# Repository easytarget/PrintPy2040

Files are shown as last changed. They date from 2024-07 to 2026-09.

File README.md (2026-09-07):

### Same Idea; different MCU
(this project is a 2024 re-working for my original, obsolete,  [PrintEYE](https://github.com/easytarget/PrintEye) project.)

# Proudly Presenting the PrintPy.

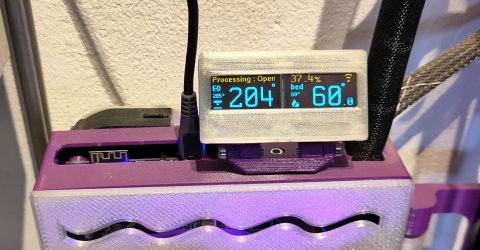
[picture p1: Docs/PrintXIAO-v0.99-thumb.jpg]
PrintXIAO in action


A dedicated Output / Display device for 3d printers running RepRapFirmware v3.4.0 and later.

It displays the current machine mode, current job status, network status, info messages and temperature plus status of the extruder and chassis heaters.
* Supports Single or Dual extruders.
* Supports Heated beds and Heated Chambers.
* Shows when a heater is in a fault state

It uses two OLED displays for it's output, and these can be configured to turn off automatically in certain states (eg *off* / *idle*).

There is a button on the rear of the unit; this can wake the display for a (configurable) time when pressed.

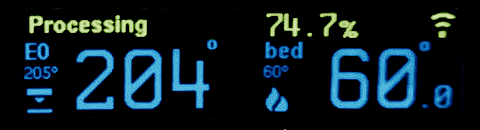
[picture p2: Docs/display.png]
Display detail


Wifi / Ethernet connection status is displayed, and the rear button can enable or disable the network as appropriate on a long press (configurable).

Messages set by `M117` and `M291` are displayed in a scrolling box along with the machine state.

Job progress is displayed when *processing*, *simulating*, *paused* etc.. The IP address or interface (error) status is displayed otherwise.

The onboard NeoPixel on the XiAO board is used to flash the current status after each update; it changes color depending on the printer 'mood':
- 🔴 Red for machine or network *errors*, 🟡 Yellow for *off*, 🟢 Green for *idle*, ⚪ White while *busy*, 🟣 Purple when *processing* jobs and 🔵 Blue for *paused* states.

# Hardware
This is designed to be a relatively simple build using commonly available inexpensive parts.

It needs some soldering and 3d printing skills, and care, but little more; there are no custom PCB's or parts.

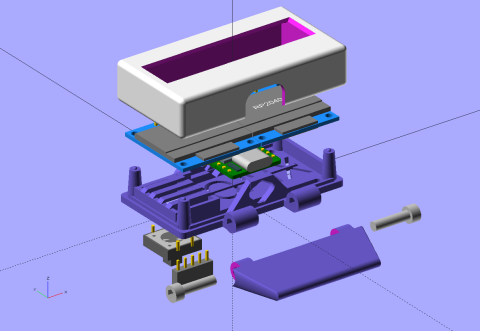
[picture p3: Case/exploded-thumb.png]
Case Render


An alternate, angled, 'foot' design with a mounting hole is included in the models; the upper case is printed from Neutral (translucent) material to allow the NeoPixel to be seen.

See the [HARDWARE](HARDWARE.md) document for a parts list, important construction notes, wiring diagrams and more.

# Software
Code for the SeeedStudio XIAO RP2040 is in the [micropython](microPython) folder.

The code represents the majority of the work needed to create this, the hardware is simple, the code less so. It is written in a well structured and modular way; the output is driven by self-contained classes that can be used as templates for alternative displays and hardware.

See the [micropython README](microPython/README.md) document for install and comissioning details; plus some architecture / development notes.

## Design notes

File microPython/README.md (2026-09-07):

# Micropython code
PrintPY is coded in [MicroPython](https://micropython.org/); and is intended to be uploaded by the user from a suitable IDE (tested with Thonny, but ViperIDE is also nice for more experienced developers).

* If this is new to you I suggest you start with the [XIAO2040 micropython guide](https://wiki.seeedstudio.com/XIAO-RP2040-with-MicroPython/) from SeeedStudio, and use [**Thonny**](https://thonny.org/) as an IDE.
 * You do not need to know Python programming, updating the firmware is drag-n-drop in your file manager, the IDE's are easy to use.
* [**Viper IDE**](https://viper-ide.org/) is also excellent; it runs from the web directly in your web browser without needing to be 'installed'.

Just as the Hardware document assumes you can 3d Print, solder and read a wiring diagram; this document assumes you can follow the guides, set up and connect to your device without needing super detailed instructions here; the guide above will show you what you need.

# RRF config:
You need to set up the second serial (UART) port on your printer to 'no CRC/checksum, 230400 baud'.
* For testing you can use the console to send:
* `M575 P1 B230400 S0`
* For a Duet2 or 3 machine using the default (panelDue) UART interface your `config.g` needs to include that line.
  * This can normally go after the USB port setting (*M575 P0 ....*) line.
  * Later Duet models have additional UART ports that could be used; you will need to adjust ['M575'](https://docs.duet3d.com/User_manual/Reference/Gcodes#m575-set-serial-comms-parameters) as necesscary for them.
* Do not omit or change the `S0` parameter; PrintPY is not compatible with CRC or Checksumming.

# RP2040 MicroPython Firmware:
Hold the 'boot' button on the XIAO board while connecting it to a USB port on your computer; it will appear as a new disk drive (just like a USB thumb drive).
* Flash with the Firmware `.uf2` file in the 'Firmware' folder by dragging and dropping that onto the XIAO drive. The XIAO will pause for a few seconds ingesting the file, then reboot.
  * ..or you can use a later firmware from the main MicroPython site
  * the version in this repo is the Firmware I have tested with
* After sucessfully flashing you should see the REPL console of the device in your IDE:
```python
  MicroPython v1.29.0 on 2026-08-24; Raspberry Pi Pico with RP2040
  Type "help()" for more information.
  >>>
```
# Installing:
Upload all the `.py` files from this directory onto the root folder of your device in the IDE; also copy the fonts directory to 'fonts'.
* The 'Firmware' folder should not be copied; you don't need to copy the README's either..

## Initial Configuration:
Copy `config-default.py` to `config.py` on the device.
* If you are using alternate hardware pins etc. you will need to adjust the hardware config definitions here
* See the [config](#Config) section below for more.

# Test Hardware:
*Note: The hardware test script will read its configuration from the config file we created above.*
* Run `hwTest.py`:
```console
Testing printXIAO comms, screen, pixel and button
UART initialised
Button present on: GPIO2
sent: M122
recieved: b'{"seq":28720,"resp":"=== Diagnostics ===\\n"}\n{"seq":28721,"resp":"RepRapFirmware for Duet 2 WiFi/Ethernet version 3.5.4 (2024-11-24 10:43:42) running on Duet WiFi 1.02 or later\\n"}\n{"seq":28722,"resp":"Board ID: UUID\\n"}\n{"seq":28723,"resp":"Used output buffers: 3 of 26 (16 max)\\n"}\n'
button: Pressed
sent: M122
recieved: b'{"seq":28810,"resp":"=== Diagnostics ===\\n"}\n{"seq":28811,"resp":"RepRapFirmware for Duet 2 WiFi/Ethernet version 3.5.4 (2024-11-24 10:43:42) running on Duet WiFi 1.02 or later\\n"}\n{"seq":28812,"resp":"Board ID: UUID\\n"}\n{"seq":28813,"resp":"Used output buffers: 3 of 26 (16 max)\\n"}\n'
sent: M122
..etc..
```
* You should see the OLED displays outlined and showing 'left' and 'right' as appropriate; the NeoPixel shuld be cycling R->G->B, if you press the button you should see a 'button: pressed' message on the REPL console.
* The script sends [`M115`](https://docs.duet3d.com/User_manual/Reference/Gcodes#m115-get-firmware-version-and-capabilities) every few seconds to the connected RRF machine; and then returns the (JSON encoded) output to the REPL console:

If you do not see any serial output the first thing to do is test (swap) the polarity of the RX and TX lines by reversing the connector on the PrintPY.
* The second thing to test is that both the PrintPy and RRF controller have the baud rate configured properly.

If you see:
```console
Failed to start displays!
[Errno 5] EIO
```
..this indicates a wiring or configuration problem with the OLED displays, the I2C controller is failing to get a response from them during initialisation.

# Commissioning:
Once the test script is running correctly you can try running `printXIAO.py`. You should now see a brief splash-screen and then the current printer status displayed. On the console you should see:
```console
printXIAO is starting
UART initialised
starting output
connected to ObjectModel
button present on: GPIO2
PrintPY::printXIAO is running
[519ms, 112000b] Up: 3d:12h:52:47 | Off | ip: 10.0.0.30
[504ms, 112000b] Up: 3d:12h:52:48 | Off | ip: 10.0.0.30
[505ms, 112000b] Up: 3d:12h:52:49 | Off | ip: 10.0.0.30
etc..
```
The (default configured) status lines show:
* [Fetch cycle time, free memory after fetching and collect()ing]
* Uptime reported by the Controller firmware
* Main status | Wifi Status | Job Progress (if any) | System messages (if any)

The Neopixel will be flashing with the printer 'mood', the heartbeat LED should be cycling as requests are sent.

## Dealing with multi-thread reset errors on the RP2040!
This is annoying; the RP2040 micropython port does not handle multi-cpu systems properly when they have threads running on the second CPU.

*Once the main printXIAO code is running you can interrupt the main loop by pressing **ctrl-c** in the REPL console, but this fails to fully 'soft reset' the board.*
1) *'Crtl-c' in the repl console should be followed immediately by running `machine.reset()` to fully reset the hardware.*
2) *or Press the reset button on the XIAO board (it's tiny and hard to access, especially once the wiring is done, use a small non-conductive plastic rod to do this)*
3) *or Force the reset by unplugging it completely from the printer and usb-c.*

*If you do not do this there is a high chance the board will quickly stop responding to REPL commands; it gets into some sort of bad USB state. This plagued me during the last stages of development.*

# AutoStart at boot
Enable running at boot time by editing the last four lines of the config as described in the comments. Then mount on your machine, close the case, and enjoy seeing your printers status at-a-glance.

*Once Autostart is enabled the multi-thread errors discussed above are more serious since the code is starting automatically. The solution is pressing **ctrl-c** quickly after the reset/reboot, before the main code loop starts. This is why there is a startup countdown, to give console users a chance to interrupt the code *before* the second CPU thread starts.*

# Architecture
`printXIAO.py` is the main program; it runs a continual loop that queries the RRF controller to fetch the current objectModel (machine state). It then calls two output class modules to display data from the objectModel:
- `lumenXIAO.py` : Shows the controller status using the onboard NeoPixel on the Xiao RP2040 board.
- `heartbeatXIAO.py` : Shows a communication 'heartbeat' using the auxillary RGB led on the board.
- `outputI2Cx2.py` : Displays the machine state on a twin OLED display, showing the overall status; current temperatures and heater statuses; job status (when active), messages and network status.
  - The display is built entirely out of fonts (using symbol fonts where necesscary) and uses my own microPython fonts, font writer and marquee.
  - Single or Twin extruders are supported, as are systems with enclosures.

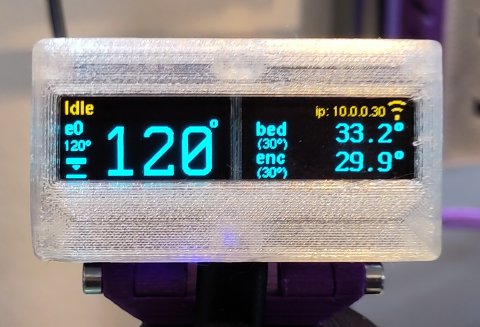
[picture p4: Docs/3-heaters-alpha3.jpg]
Alpha demo


# Requirements:
There are no external dependencies or requirements needed, this folder contains the `printXIAO` code itself and all the libraries it uses.

### SerialOM
Development of the communications code happens in the `serialOM` repo:
https://github.com/easytarget/serialOM

### EZfont Libraries and fonts are in the `fonts` folder
Development of the Font display system (Font Writer, Marquee and the Fonts themselves) happens in the `microPyEZfonts` repo:
https://github.com/easytarget/microPyEZfonts

## Config
As noted above, you need to copy `config-default.py` to `config.py` in the root folder of your device.

Then make any changes you might want.
* See the comments in the config file.
* There are not many 'user options' to play with, and the defaults are set up sensibly for the XIAO 2040 board used here.
* You can set the list of states where the Display should turn off:
  * OLED displays can [burn in](https://forum.makerforums.info/t/oled-display-burn-in-the-evidence/90223) if left on all the time, making the output look reaaly ugly!
  * Turning the displays off when the Printer is `off` is a very good idea.
  * If your printer is permanently on it may be a good idea to add `[idle]` as well as `[off]` to the list of screen off states.
* Another important option here is the Baud rate for the serial port; you must match the speed with the speed configured on your controller. The default baud rate for PrintXIAO is 230400 baud, no parity.
* Only mess with the Hardware settings if you are using alternate wiring or boards etc..
* Do not try to 'speed up' the main (once per second by default) fetch/update cycle too much, the cpu needs at least 500ms to do each fetch cycle, plus 150ms to render the updates to the display panels.
* NeoPixel and display brightnesses can be set, you may want to reduce these in a dark workshop. You can set a different brightness for 'off states'.
* The default network interface can be defined (for controllers with more than one) as can the default commands sent to enable/disable the network.

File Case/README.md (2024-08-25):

# A PythonSCAD based case design.

[PythonSCAD](https://pythonscad.org/)

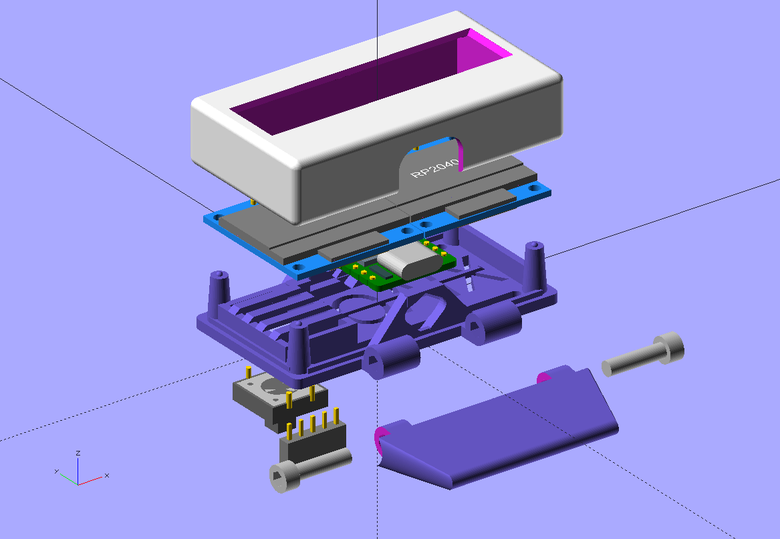
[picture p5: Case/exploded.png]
Case Render


This is also the beginning of a pythonSCAD parts library for my projects

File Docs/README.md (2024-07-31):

## PrintPy notes and references

# Useful Links

ObjectModel reference:
https://github.com/Duet3D/RepRapFirmware/wiki/Object-Model-Documentation

How to detect Object model updates:
https://forum.duet3d.com/topic/16703/suggestions-for-the-object-model/3
https://forum.duet3d.com/topic/30448/how-to-detect-board-disconnection/2

Good background:
https://forum.duet3d.com/topic/25300/how-to-dump-the-entire-object-model

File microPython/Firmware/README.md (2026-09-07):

# Reference firmware package from micropython download site

A copy is kept here for reference; this is the current firmware I am using on my RP2040, and the code has ben extensively tested on this.

```
SEEED_XIAO_RP2040-20260824-v1.29.0.uf2
```

This Upstream (vanilla) firmware was downloaded from the MicroPython downloads page:
https://micropython.org/download/SEEED_XIAO_RP2040/

The `SEEED_XIAO_RP2040-20260824-v1.29.0.atexit.uf2` firmware was built by me; it enables the `atexit()` function within micropython for catching all `exit()` events. This is handy for stopping threads, cores and timers in multi-thread code such as PrintPY; and is detected and used to give smoother debugging if available.

Now this project is released I do not intend to track, upgrade and test every new MicroPythoin release.

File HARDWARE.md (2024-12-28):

# HARDWARE GUIDE FOR PrintXIAO
## the the default PrintPY implementation

Case Render

## Parts:
1. A SeeedStudio XIAO RP 2040 devboard
2. Two SSD1306 OLED I2C displays; the yellow/blue displays I use in my project work well, but any color display of the same size will work.
3. Hookup wire; thin.
4. (optional) A press Button; the design used here is quite common, the case has enough space to accomodate other types
5. (optional) A 5-pin du-pont socket strip, I had to cut down and trim a longer strip.
  * Alternatively you can have a direct wire from the PrintPY to the board, depending on needs.

You will also need a UART cable suitable for your board, the cable below is for a Duet2.
* The Duet3+ ranges use a different JST plug on the board. This has 3.3v available avoiding the need to bring 5V to the PrintPY, see the notes at the end of this document for more

## Case
The case needs care when slicing and printing, some of the clearances are very tight. use a slicer with adaptive layer height features to make sure the screens and PCB's fit correctly.

Print the upper case from neutral translucent material if you can. The onboard NeoPixel 'mood indiator' will then illuminate the whole body. You could also cut 'windows' in the case for illumination, or disable the mood lighting entirely in the config if not wanted.
- There are two upper case models included. One has a cutout allowing access to the XIAO USB-C port (for developing and debugging) while the other is a continuous shell and will probably print 'better' (fewer atrifacts in the translucent print) and grip in place more securely. ymmv.

The STL file has all the components included and orientented correctly, edit it in your slicer to select only the components you are going to print.
- There are two 'foot' designs included, one for freestanding use, the other is more suited to a frame mounting.

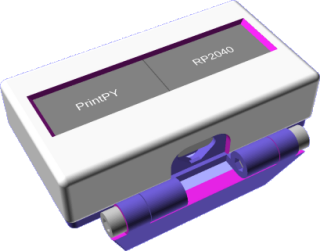
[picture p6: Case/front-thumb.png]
Case Render
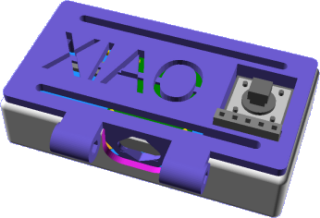
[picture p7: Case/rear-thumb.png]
Case Render
 

There are *three* case sizes, I used the 'slim' case, the only difference for the 'normal' and 'large' varients is that they add 2mm and 4mm (respectively) of additional depth (wiring space) between the screens and the Xiao/connections.
- I recommend using the 'normal' case, the slim design packs the hookup wiring *very* tightly and is hard to get cosed without springing back open (I eventually lightly glued mine together once I'd verified all the wiring, buttton etc).

### Important Construction Note:
Print the top case from a translucent material to allow the Neopixel and heartbeat LED's to be seen through the case.

You need to 'mask' the gap between the two OLED displays, otherwise this will look ugly with a bright light coming through the gap.
- Use a strip of opaque tape, I cut a strip of very ordiary black electrial tape for this.
- I then placed tape across all the exposed electronics on the back of the display to insulate them and then placed a strip of silver foil on that so that the NeoPixel is reflected back to maximize the lighting effect.

You also need to mask (or remove) the 'Super Brite!' 5V power LED on the Xiao board. This destroys the lighting effect otherwise.
- To be honest; Seeedstudio screwed up here. They put this very bright LED right next to the relatively dim RGB status LED that I use for a 'heartbeat' display. The RGB is essentially invisible when the board is running from a 5V supply.
- I cut and heat-formed a very small square of black plastic which is glued in place, this was fiddly since the LED also shines out sideways from it's package, so I had to make a 'cap' that fits over it.
- Desoldering it would be preferable, but it is in a very fiddly location and extremem cre would be needed, plus a good magnifier.

After wiring consult the code install and comissioning document *before* you close the case and mount the unit. As well as attaching a USB-C cable for programming, you will need to access the reset button on the XIAO board as part of comissioning.

## Wiring 5V (Duet 2)
Hookup Guide

There is no PCB needed for this, the circuit should be wired + soldered directly in-place using thin hookup wire (this is fiddly, but possible)

## Connecting to Duet / RRF board.
PrintPY connects to the UART (serial) port on your board. It needs a Power Supply, ground and TX/RX connections.

[The documentation for the PanelDUE also gives a good overview of connecting serial to the Duet boards, there is a specific PanelDue `UART` socket on the Duet2 (wifi), and the `IO_0` socket on the Duet3 boards.

### Connection Looms; 5V (Duet)
Take care with wiring this, it is important that the 5V supply does not contact the (3v3) TX/RX lines! The connector allows the plug to be reversed to swap TX/RX lines quickly and safely.

#### Duet 2
Duet2 Loom

#### Duet3
Duet3 Loom
(Serial connection loom diagrams were generated by [wireviz](https://github.com/wireviz/WireViz) from the `.yaml` descriptions [here](Docs/wireviz_uart_duet2.yaml) and [here](Docs/wireviz_uart_duet3.yaml))

### 3.3V Looms
If you have a board with a 3.3v pin on the uart connector (like the Duet3) you can adapt the main wiring so it does not use 5V at all:
- Leave the 5V pin on the XIAO unconnected
- Bring the 3.3V power rail to the rear connector of the PrintPY in place of the 5V one
- Adapt the Duet3 loom (above) as needed..
- I leave this as an excercise for the reader..

## Alternate connections/deployments
The software is pretty modular; the OLED displays and NeoPixel are driven by self-contained classes. The main PrintPY code loop updates the local objetModel and then calls the lumen and display modules; the modules themselves decide what to display based on the current objectModel status.

It would be relatively easy to re-write the `output` and `lumen` modules for other displays and purposes.

### RP2040 I2C pins
If using an alternate RP2040 board please check the table below to determine which pins the I2C interfaces can be accessed on; and make sure the pins are correctly defined in the code.
```
I2C0 – SDA : GP0 / GP4 / GP8  / GP12 / GP16 / GP20
I2C0 – SCL : GP1 / GP5 / GP9  / GP13 / GP17 / GP21
I2C1 – SDA : GP2 / GP6 / GP10 / GP14 / GP18 / GP26
I2C1 – SCL : GP3 / GP7 / GP11 / GP15 / GP19 / GP27
```

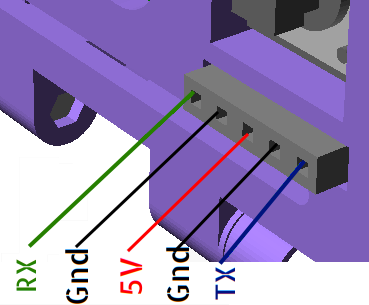
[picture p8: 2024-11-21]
Docs/uart-connector.png

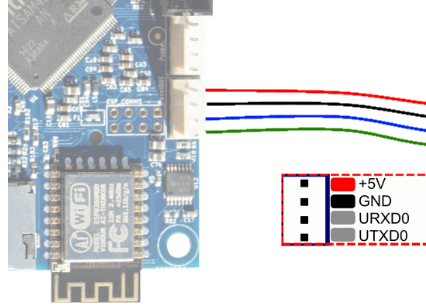
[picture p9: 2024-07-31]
Docs/duet2-uart1.png

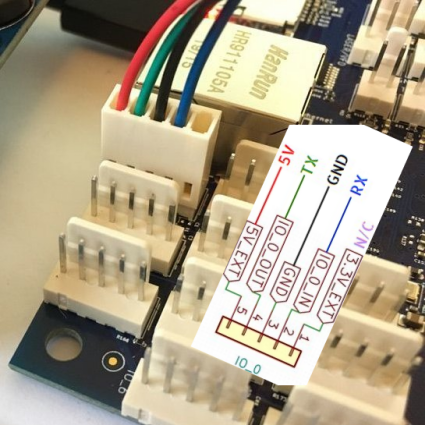
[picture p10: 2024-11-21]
Docs/duet3-uart1.png

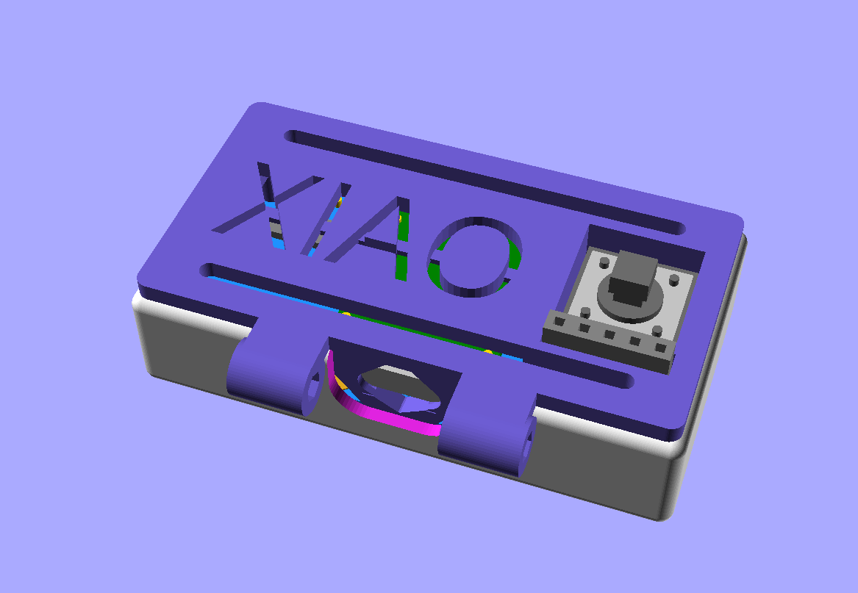
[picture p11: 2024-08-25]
Case/rear.png

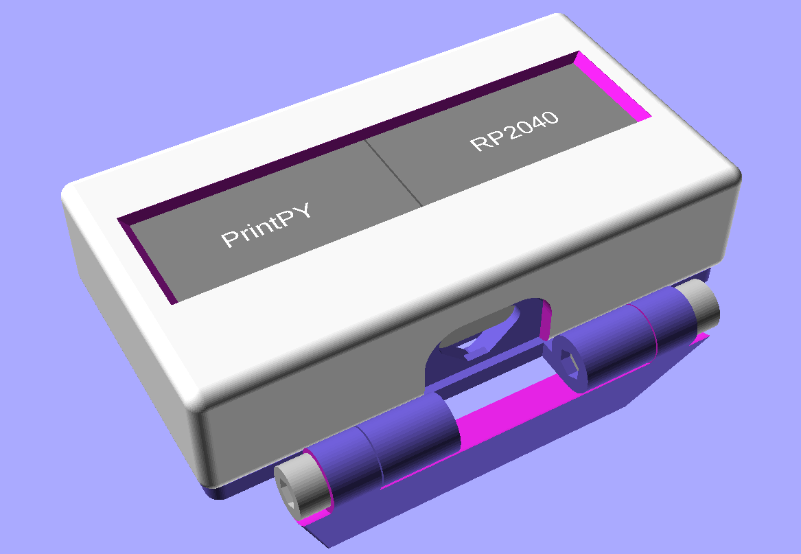
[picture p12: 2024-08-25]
Case/front.png

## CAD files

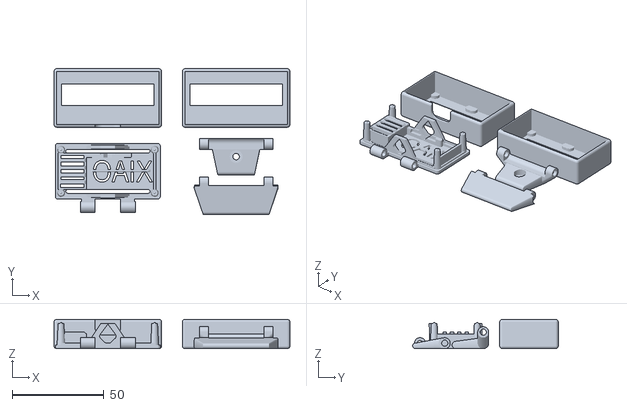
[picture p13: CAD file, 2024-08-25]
Case/PrintPy2040-Case-normal.stl
128.8 x 79.5 x 16.0

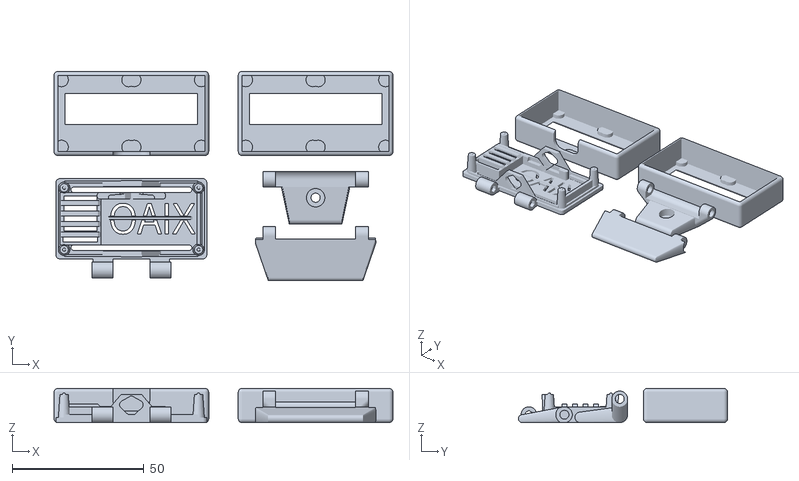
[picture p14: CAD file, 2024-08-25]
Case/PrintPy2040-Case-slim.stl
128.8 x 79.5 x 13.0

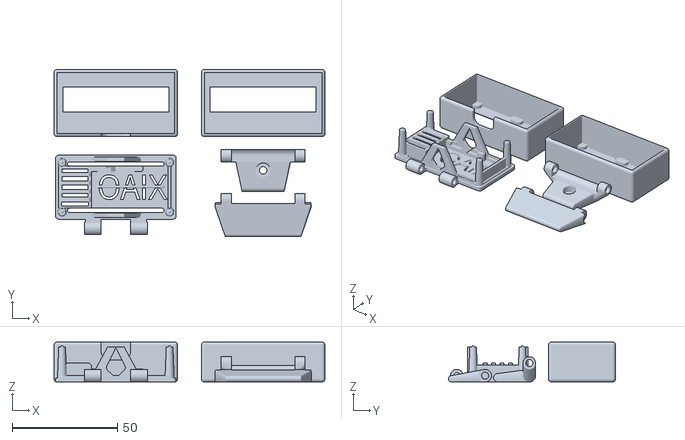
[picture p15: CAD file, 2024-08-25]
Case/PrintPy2040-Case-large.stl
128.8 x 79.5 x 19.0

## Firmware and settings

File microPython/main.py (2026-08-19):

# main.py
#
# Place this in the root filesystem of the device, it
# examines config.py to determine whether to autostart
# printXIAO on device startup and hard reboots.

def countDown(text, time):
    print('{}: '.format(text), end='')
    for i in range(time,0,-1):
        print('{}'.format(i), end='')
        sleep_ms(500)
        print('.', end='')
        sleep_ms(500)
    print('now')

def run():
    try:
        import printXIAO
    except Exception as e:
        print('PrintXIAO.py exited:\n{}\n'.
              format(e))
        countDown('Waiting for display watchdog', config.display_watchdog + 1)


print('PrintXIAO loader')
from time import sleep_ms
from machine import reset
try:
    from config import config
except ModuleNotFoundError:
    print('Cannot find config.py')
    print('Copy "config-default.py" to "config.py" and edit as needed')
else:
    if config.autostart is not None:
        while True:
            countDown('Autostart', config.autostart)
            run()
            reset()

# drop out to the repl prompt
print('Debug mode; (use "import printXIAO" to start)')

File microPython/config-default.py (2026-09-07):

'''

RENAME/COPY this file to `config.py` on your device
- edit if needed, defaults are sensible ones for a XIAO2040 based device
- button definition and display swapping is done here.

'''

from machine import UART, Pin, I2C

class config():
    '''
        UI:
        update_time:  (float) MINIMUM time interval between data update cycles (seconds)
        Note: on the RP2040 version of printPY it currently takes approx. 500ms to fetch
            and ingest the OM, then another 150ms to update the display buffer.
        off_states:   (list) states where the screen should turn off
                      - set to an empty list '[]' to keep permanently on
                      - set to '['off','idle']' to only turn on when active
        sleep_time:   (float) screen standby off time (seconds)
        long_awake:   (float) wakeup time when button is pressed or status changes
        button_long:  (float) button long press time (seconds) for WiFi toggle, 0 to disable
        splash_time:  (float) splash screen time in seconds
    '''
    update_time  = 0.5
    off_states   = ['off']
    sleep_time   = 10
    long_awake   = sleep_time * 3
    button_long  = 2.5
    splash_time  = 3

    '''
        Hardware config:
        button:      Status button pin object
                     (set '= None' to disable)
        button_down: Pin value when button depressed
        I2C_left:    I2C interface definitions for left and right screens
        I2C_right:   Currently uses default pins and hardware interfaces and
                     can be adapted with softI2C+alternate pins as needed.
        pixel_pin:   Onboard NeoPixel pin
        pixel_power: Neopixel VCC is turned on via this pin on the XIAO
    '''
    button      = Pin(2, Pin.IN, Pin.PULL_UP)
    button_down = 0
    I2C_left    = I2C(1, sda=Pin(6), scl=Pin(7))
    I2C_right   = I2C(0, sda=Pin(28), scl=Pin(29))
    pixel_pin   = Pin(12)
    pixel_power = Pin(11,Pin.OUT)

    '''
        Serial Device Config:
        device: UART device
        baud:   (int) Serial baud rate; should match the setting used in config.g
                - for example: M575 P1 B230400 S0
    '''
    device = UART(0)
    baud   = 230400

    '''
        Network Config:

        NOTE: Defaults here assume a WiFi enabled board that connects to a client network.
              You will need to adjust as needed if you have an Ethernet board (no -1 disabled state..),
              connect to a specific network (the 'P' option to M552) or run as an Access Point.

        net:      (int) Default Network Interface number
                  - (`None` to disable network status display and functions)
        net_map: (dict) defines the 'wifi toggle' button press command
                  to be sent to the machine for each wifi state defined in the OM
                  - The '{NET}' will be replaced by the network number given above
                  - The list of possible states is defined in:
                    https://github.com/Duet3D/RepRapFirmware/wiki/Object-Model-Documentation#networkinterfacesstate
                  - If the network state is not specifically matched the DEFAULT entry will be used.
                  - https://docs.duet3d.com/User_manual/Reference/Gcodes#m552-set-ip-address-enabledisable-network-interface
    '''
    net     = 0
    net_map = { 'disabled' : 'M552 I{NET} S1',
                 'DEFAULT' : 'M552 I{NET} S-1',}

    '''
        Display hardware settings
        display_bright: (float) Display Brightness (0 to 1)
        display_invert: (bool) Invert display colors
        display_rotate: (bool) Flip display vertically
    '''
    display_bright = float(0.66)
    display_invert = False
    display_rotate = True

    '''
        NeiPixel 'mood' illumination
        mood:         (bool)  Indicate status via onboard Neopixel
        mood_bright:  (float) Indicator LED brightnessx (0 to 1)
        mood_standby: (float) Indicator LED brightness when machine off
        mood_flash:   (int)   Mood indicator flash time (ms)
                              0 = permanent on
    '''
    mood         = True
    mood_bright  = float(1.0)
    mood_standby = float(0.2)
    mood_flash   = 12

    '''
        Communications heartbeat on auxillary RGB
        heart          (bool)  Show comms heartbeat
        heart_bright:  (float) Heartbeat LED brightness (0 to 1)
        heart_standby: (float) Heartbeat LED brightness when machine off
    '''
    heart         = True
    heart_bright  = float(1.0)
    heart_standby = float(0.75)
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

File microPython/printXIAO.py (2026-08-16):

# Import our local classes and config
from serialOM import serialOM
from outputI2Cx2 import outputRRF
from lumenXIAO import lumen
from heartbeatXIAO import heartbeat
from config import config

# The microPython standard libs
from sys import exit
from gc import collect, mem_free
from machine import reset
from time import sleep_ms, ticks_us, ticks_diff, ticks_add, localtime

# timers are in microseconds
TIMESCALE = 1000000  # == 1 second

'''
    PrintMPy is a serialOM.py loop for MicroPython devices.
'''

# Placeholder objects for timers and IRQ's; declared here so
# that we can safely test for and disable as needed whenever we exit.
button = None
button_time = None
animator_thread = None
mood = None
heart = None

# local print function so we can suppress info messages.
def pp(*args, **kwargs):
    if config.verbose:
        print(*args, **kwargs)

def buttonPressed(_p):
    # ISR: Any button activity triggers this; does not need debouncing.
    # - we check for a long button press in the main loop.
    global button_time     # we are in an interrupt, bring this into context
    if config.button_long > 0:
        button_time = ticks_add(ticks_us(), int(config.button_long * TIMESCALE))
    out.awake(int(config.long_awake))

def buttonLong(button_time):
    # has the button been long-pressed?
    if button_time is not None:
        if button.value() == config.button_down:
            if (ticks_diff(ticks_us(), button_time) > 0) and (config.net is not None):
                networkToggle()
                return None
            else:
                return button_time
    return None

def networkToggle():
    if OM.model is None:
        return
    if len(OM.model['network']['interfaces']) == 0:
        return
    interface = OM.model['network']['interfaces'][config.net]
    if interface['state'] in config.net_map.keys():
        cmd = config.net_map[interface['state']]
    else:
        cmd = config.net_map['DEFAULT']
    cmd = cmd.replace('{NET}',str(config.net))
    net = interface['type']
    pp('{} change requested via button: {}'.format(net, cmd))
    out.awake(config.long_awake)
    OM.sendGcode(cmd)
    out.alert()

def restartNow(why, message='PrintPY\nerror'):
    # Do a minimum drama restart/reboot, mostly useful so we
    # get a re-check-loop at startup if comms are failing
    # - really unlikely to get called otherwise..
    pp('Error: ' + why)
    pp('Restarting in ',end='')
    for c in range(config.reboot_delay,0,-1):
        pp(c,end=' ')
        if config.mood:
            mood.blink('err', out.standby, False)
        out.showError(message, 'Restarting\nin: {}s'.format(c))
        sleep_ms(1000)
    pp()
    out.off()
    if config.debug is not None:
        print('Debug mode: exiting to REPL')
        killAll()
        exit()
    else:
        reset()  # Reboot module

def hardFail(why):
    # Fatal error; halt.
    pp('A critical hardware error has occured!')
    pp('- Do a full power off/on cycle and check wiring etc.\n' + why + '\n')
    while True:  # loop forever
        sleep_ms(60000)

def killAll():
    # attempt to kill the animator threads, button IRQ
    # and notification LEDs. Useful when debugging.
    print('exit(): killing background')
    try:
        out.watchdog = 0   # for completeness..
        # kill the animator thread
        animator_thread.exit()
    except:
        pass  # dont care, we are exiting
    try:
        # Remove the button IRQ
        # (allegedly.. docs not really clear about this)
        button.irq(handler=None)
    except:
        pass  # dont care, we are exiting
    # Mood and heartbeat LED's off
    try:
        mood.off()
    except:
        pass  # dont care, we are exiting
    try:
        heart.off()
    except:
        pass  # dont care, we are exiting

# Firmware with atexit() enabled might help debugging..
# but to be honest.. it doesn't really help.
# I'm not sure if the call to killAll is being made,
# it does not print() on the repl console to say it ran..
try:
    from sys import atexit
    atexit(killAll)
except:
    pp('Firmware does not support atexit() handler')


'''
    Init
'''

# Always log that we are starting to console.
print('printXIAO is starting')

# LEDs
if config.mood:
    mood = lumen(config.mood_bright, config.mood_standby, config.mood_flash)
if config.heart:
    heart = heartbeat(config.heart_bright, config.heart_standby)

# UART connection
rrf = config.device
rrf.init(baudrate=config.baud)
if not rrf:
    hardFail('No UART device found')
else:
    pp('UART initialised')
# UART port and buffer will be in a unknown state; there may be junk in it
# So; send a newline, then wait a bit (display init), then empty the buffer
rrf.write('\n')
rrf.flush()

# Get output/display device, hard fail if not available
pp('starting output')
out = outputRRF()
if not out.running:
    hardFail('Failed to start output device')
out.splash()
out.on()
splashend = ticks_add(ticks_us(), int(config.splash_time * TIMESCALE))

# Now that the display is running we read+discard from the UART until it stays empty
while rrf.any():
    rrf.read(128)
    sleep_ms(100)

# create the OM handler and get initial status
try:
    OM = serialOM(rrf, out.omKeys, quiet=config.verbose, noCheck=True)
except Exception as e:
    restartNow('Failed to start ObjectModel communications\n' + str(e),
               'Connection\nError')

# Initial model fail
if OM.machineMode == '' or OM.model is None:
    restartNow('Failed to connect to controller, or unknown controller mode.',
               'Failed to\nConnect')

pp('connected to ObjectModel')

# hardware button
button_time = None
if config.button is not None:
    button = config.button
    button.irq(trigger=button.IRQ_FALLING | button.IRQ_RISING, handler=buttonPressed)
    pp('button present on:',repr(button).split('(')[1].split(',')[0])

# Show initial mood
if config.mood:
    mood.blink(mood.emote(OM.model, config.net), out.standby, True)

# Put initial data into panels (it wont be displayed until splash ends)
out.updatePanels(OM.model)

# pause for splash timeout
while ticks_diff(ticks_us(), splashend) < 0:
    sleep_ms(25)

pp('PrintPY::printXIAO is running')

# end splash,
out.off()

# Start the marquee and model output (will run in a new thread)
animator_thread = out.animator()

# Pause for long enough that the animator completes its initial cycle
sleep_ms(100)

# Show initial update
out.on()
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

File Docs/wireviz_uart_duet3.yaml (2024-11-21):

connectors:
  Duet3:
    type: MOLEX KK 254
    subtype: female
    pinlabels: [5V, IO_0_OUT (TX), GND, IO_0_IN (RX), N/C (3.3V)]
    image:
      src: duet3-uart1.png
    notes: "This is a polarised plug\nTX and RX are NOT 5V tolerant!\nCare Needed"
  PrintPY:
    type: 2.54mm PINSTRIP
    subtype: male
    pinlabels: [RX, GND, 5V, GND, TX]
    image:
      src: uart-connector.png
    notes: Gnd pins 2 and 4 are connected internally
    #loops:
    #  - [2, 4]

cables:
  Serial:
    gauge: 0.2 mm2
    length: 0.30
    colors: [RD, BK, BU, GN]
    wirecount: 4
    shield: true
    notes: "Shield is optional\nMay be needed for long runs"

connections:
  -
    - Duet3: [1,3,4,2]
    - Serial: [1,2,3,4]
    - PrintPY: [3,4,5,1]
  -
    - Duet3: 3
    - Serial: s

options:
  color_mode: full

metadata:
  notes: https://docs.duet3d.com/User_manual/Connecting_hardware/Display_PanelDue

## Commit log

2023-12-28 Initial, case
    [PrintPy2040-Case.scad]
2023-12-30 fixup failed merge
    [PrintPy2040-Case.scad]
2024-01-01 New Foot
    [PrintPy2040-Case.scad]
2024-01-01 Big Foot
    [PrintPy2040-Case.scad]
2024-01-01 Slimmer case
    [PrintPy2040-Case.scad, PrintPy2040-Case.stl]
2024-01-02 case mods
    [PrintPy2040-Case.scad]
2024-01-02 improve mcu plate
    [PrintPy2040-Case.scad]
2024-01-02 nearly there
    [PrintPy2040-Case.scad, PrintPy2040-Case.stl]
2024-01-03 tweaks after testing
    [PrintPy2040-Case.scad]
2024-01-03 re-work mcu support
    [PrintPy2040-Case.scad]
2024-01-04 case fiddling
    [PrintPy2040-Case.scad]
2024-01-05 new mount foot
    [PrintPy2040-Case.scad]
2024-01-05 clip work
    [PrintPy2040-Case.scad]
2024-01-05 THIS is the way (for the mcu bracket..)
    [PrintPy2040-Case.scad]
2024-01-06 adjust light pickup
    [PrintPy2040-Case.scad]
2024-01-08 This *should* be final for now
    [PrintPy2040-Case.scad]
2024-01-09 small adjust on mcu plate
    [PrintPy2040-Case.scad]
2024-01-18 Latest case and updated demo
    [PrintPy2040-Case.scad]
2024-01-24 allow screen rotate
    [PrintPy2040-Case.scad]
2024-01-25 more room for wiring
    [PrintPy2040-Case.scad]
2024-01-26 stl file for case
    [PrintPy2040-Case.stl]
2024-01-27 add RP2040 I2C mappings
2024-01-28 Hookup guide
    [printpy.fzz]
2024-02-06 rename folder
    [PrintPy2040-Case.scad, PrintPy2040-Case.stl]
2024-02-09 switch to serial, use seqs
2024-02-14 fixes and micropython prep
    [serialRRF.py]
2024-02-15 work on output flow
2024-02-18 allow for device list, default config
2024-02-19 add axes, CNC and Laser output
2024-02-19 drop early boards key fetch
2024-02-19 loop on pyserial init fail
    [serialRRF.py]
2024-02-19 output return to caller, dont print
2024-02-19 better network info and fixes
    [outputTXT.py]
2024-02-20 Work Axes and workspace, format fixes
    [outputTXT.py]
2024-02-21 failover more readily on writes
    [handleOM.py]
2024-02-22 fix missing self.seqs in handler
    [handleOM.py]
2024-02-24 better way of doing things, mode and reboot changes tolerant
    [logRRF.py]
2024-02-24 logging and quiet mode fixed
    [logRRF.py, outputTXT.py]
2024-07-27 new, better, case
    [PrintPy2040-Case.scad, PrintPy2040-Case.stl]
2024-07-27 case tweak
    [PrintPy2040-Case.scad, PrintPy2040-Case.stl]
2024-07-27 more case tweaks
    [PrintPy2040-Case.scad, PrintPy2040-Case.stl]
2024-07-27 2 cases
    [PrintPy2040-Case-slim.stl, PrintPy2040-Case.scad, PrintPy2040-Case.stl]
2024-07-31 CaseII, simpler and better
    [PrintPy2040-Case-slim.stl, PrintPy2040-Case.scad, PrintPy2040-Case.stl]
2024-07-31 WireViz for connector cable
2024-07-31 show PrintPy connector in loom
2024-08-25 final tweaks to scad design
    [PrintPy2040-Case-slim.stl, PrintPy2040-Case.scad, PrintPy2040-Case.stl]
2024-11-26 wireviz note
2024-11-29 pwm heartbeat
2024-11-30 UART clean on start, slight refactor
2024-11-30 flip the verbosity option, less verbose start
    [config-default.py, printXIAO.py]
2024-12-02 This almost works, but approach is wrong, rewrite
    [config-default.py, outputI2Cx2.py, printXIAO.py]
2024-12-03 fix timer not firing after gc.collect
    [lumenXIAO.py]
2024-12-03 threading working
2024-12-03 screen timeout, button wake
2024-12-10 better responses to button and events
2024-12-12 add led off functions
2024-12-14 heater display visual cleanup
2024-12-14 handle CNC and Laser mode gracefully
2025-01-28 fix timer, wip
2026-08-11 WIP: watchdog and animator timer now use ticks_diff()
2026-08-11 Still WIP. More changes and fixes
    [outputI2Cx2.py]
2026-08-11 working again, but neopixel broken
    [outputI2Cx2.py]
2026-08-11 more mood config fixes
    [printXIAO.py]
2026-08-11 speculative, I dont trust the neopixel driver in a thread
2026-08-15 add pauses after neopixel writes due to timer/memory issues
    [lumenXIAO.py]
2026-08-15 use long_awake for button
2026-08-16 reduce impact of timer exhaustion
2026-08-16 button handling fixup
2026-09-07 smoother case entry
